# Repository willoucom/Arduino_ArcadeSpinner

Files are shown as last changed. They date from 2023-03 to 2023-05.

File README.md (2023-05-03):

# Arduino_ArcadeSpinner

This project is a modern re-creation of the spinners used in arcades, mainly for brick-breakers like arkanoid for example.

The objective is to offer a feeling close to the original equipment by using components that are easy to obtain.

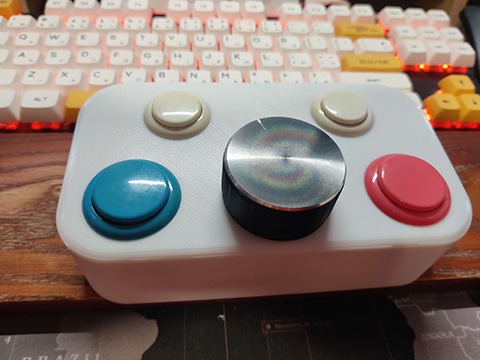
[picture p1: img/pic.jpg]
Img! Arcade Spinner


## In action

### Arkanoid with rotary controller
IMAGE ALT TEXT (http://www.youtube.com/watch?v=QnDsVMLP6zM "Arkanoid with rotary controller on MisterFPGA")

### Puzz'Loop 2 with rotary controller
IMAGE ALT TEXT (http://www.youtube.com/watch?v=TzKd8ytODUM "Puzz'Loop 2 with rotary controller on MisterFPGA")

### Eco Fighter / Ultimate Ecology with rotary controller
IMAGE ALT TEXT (http://www.youtube.com/watch?v=sb1mO-uq1ag "Eco Fighter / Ultimate Ecology with rotary controller on MisterFPGA")

## Usage

By default the device operate as a 4 button controller with Spinner/Paddle attached

You can activate an additional behavior by holding a button when you plug in the device : 

- Press Button0 (Big Left button) to enable MouseX Emulation
- Press Button1 (Big Right button) to enable Paddle Emulation
- Press Button2 (Small Left button) to switch device to mr.Spinner (enabling composite device on mister fpga)
 - In mr.Spinner mode, each button press is redirected to button 1

## MisterFPGA

### Working

| Game | Note|
|--- |--- |
| Arkanoid (World) | |
| Block Gal | |
| Breakout (TTL) | Enable spinner in controls|
| Crater Raider | |
| Dark Planet | |
| Demolition Derby | |
| Discs of Tron | |
| Eco Fighters | Use mr.Spinner mode |
| Forgotten Worlds | Use mr.Spinner mode |
| Kick | |
| Kozmik Krooz'r | |
| Midnight Resistance | Use mr.Spinner mode |
| Moonwar | |
| Pong | Use Paddle emulation and set your player to Paddle |
| Pop'n Bounce (NeoGeo) | Enable Paddle in Dip settings (Soft dip->Pop'n bounce->Controller = paddle) |
| Puzz Loop 2 | Enable Paddle in Service mode (System -> Operation) |
| Tron | |
| Two Tigers (tron conversion)  | |

### Working with workaround
| Game | Note|
|--- |---|
| Block block (world) | Use alternatives/block block (world 910910), must use Mouse Emulation |
| Super Breakout | Enable paddle in controls, must use paddle emulation |

## Mame

You can use the controller with mame and derivative by using the controller in Mouse Emulation mode.

> Note: You can define the default behavior of the controller by modifying the source code, to do this modify the default value of the variable `bool mouse_emu = 0;` to 1t which will have the effect of operating the controller in mouse mode

You need to change the `dial device assignment` option in the mame settings either in mame.ini or using the GUI.

### Edit mame.ini 
```
dial_device               mouse
```
### Using MAME GUI

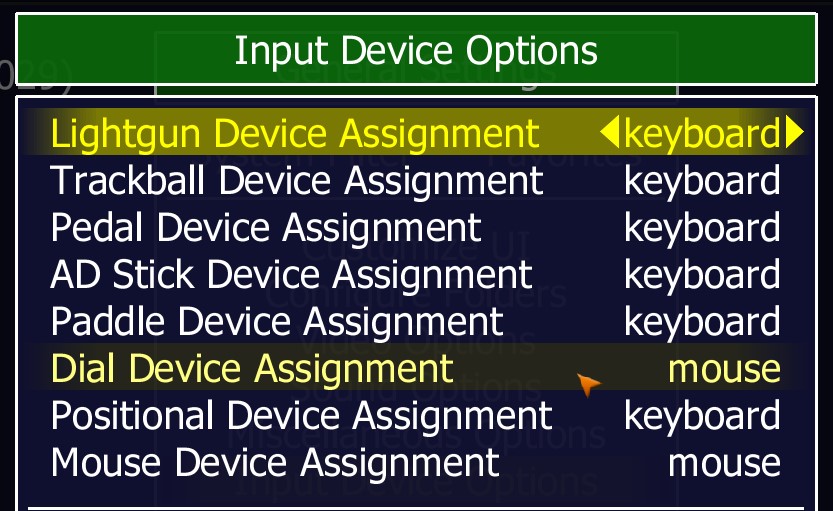
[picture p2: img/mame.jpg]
Img! MAME


## Build yourself

### Parts 

- Rotary encoder (Model: C38S6G5-600B-G24N)
- 40mm Knob with internal diameter of 6mm 
- Arduino Pro Micro
- 2 24mm button
- 2 30mm button
- Enclosure 3D printed or any box

#### Prepare the rotary encoder

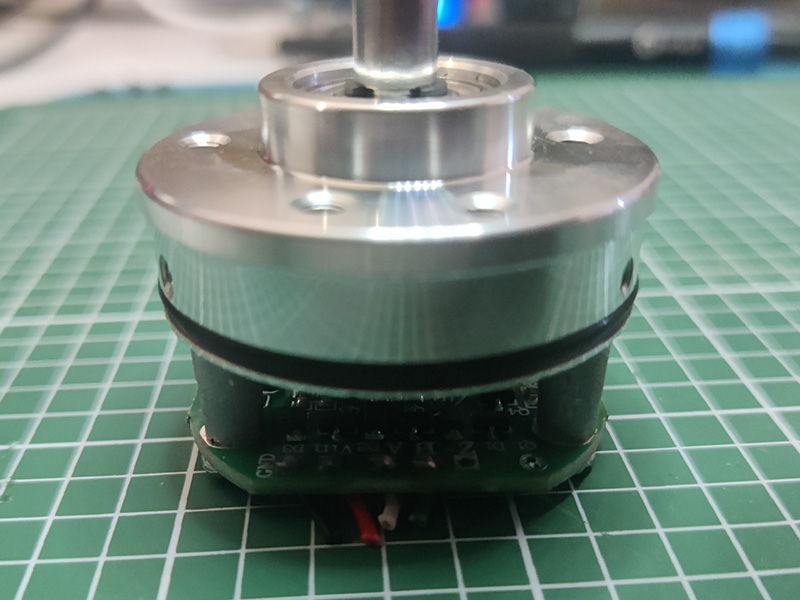
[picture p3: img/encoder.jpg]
Img! rotary encoder


1. Remove the metal enclosure and extract the mechanism.
2. Unsolder all wires.
3. Solder fresh wires on GND, VCC, A and B pads.
4. Recycle the original metal case and wire for another project.

### Arduino Pinout

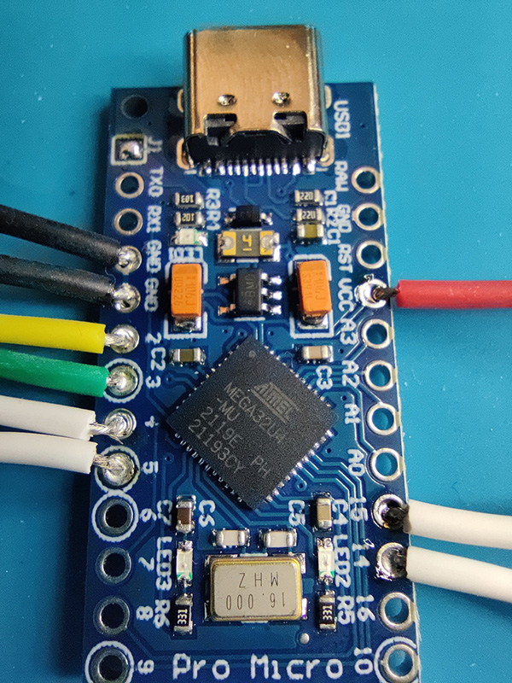
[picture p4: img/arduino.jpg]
Img! Arduino


The buttons must be grounded, you can create a daisy chain to use a common GND for your 4 buttons, you can solder the buttons or use wire connectors.

Bridge pad J1 to send +5v to encoder instead of 3.3v

```
Encoder
GND     GND
VCC     VCC
GP_3    A
GP_2    B

Buttons
GP_5    Button0
GP_4    Button1
GP_15   Button2
GP_14   Button3
```

### Flash your Arduino

1. Install Aduino IDE 2.x
2. Open Arduino_ArcadeSpinner.ino
    1. (Optionnal) Change options in the configuration section.
3. Connect your Arduino pro micro to your computer
4. Select Arduino Leonardo with the correct com port
5. Flash the controller

## Technical informations
In the mister source code there is two special cases

If the device name start by MiSTer-S1 the device is considered as a mr.Spinner

```
// mr.Spinner
// 0x120  - Button
// Axis 7 - EV_REL is spinner
// Axis 8 - EV_ABS is Paddle
// Overlays on other existing gamepads
if (strstr(uniq, "MiSTer-S1")) input[n].quirk = QUIRK_PDSP;
if (strstr(input[n].name, "MiSTer-S1")) input[n].quirk = QUIRK_PDSP;
```

If the device name start by MiSTer-A1 the device is considered as an arcade stick with a spinner and/or paddle
```
// Arcade with spinner and/or paddle:
// Axis 7 - EV_REL is spinner
// Axis 8 - EV_ABS is Paddle
// Includes other buttons and axes, works as a full featured gamepad.
if (strstr(uniq, "MiSTer-A1")) input[n].quirk = QUIRK_PDSP_ARCADE;
if (strstr(input[n].name, "MiSTer-A1")) input[n].quirk = QUIRK_PDSP_ARCADE;
```

## Rotary encoder

The rotary encoder uses a magnet to detect rotation, it translates the orientation into pulses which are then interpreted by the arduino controller.

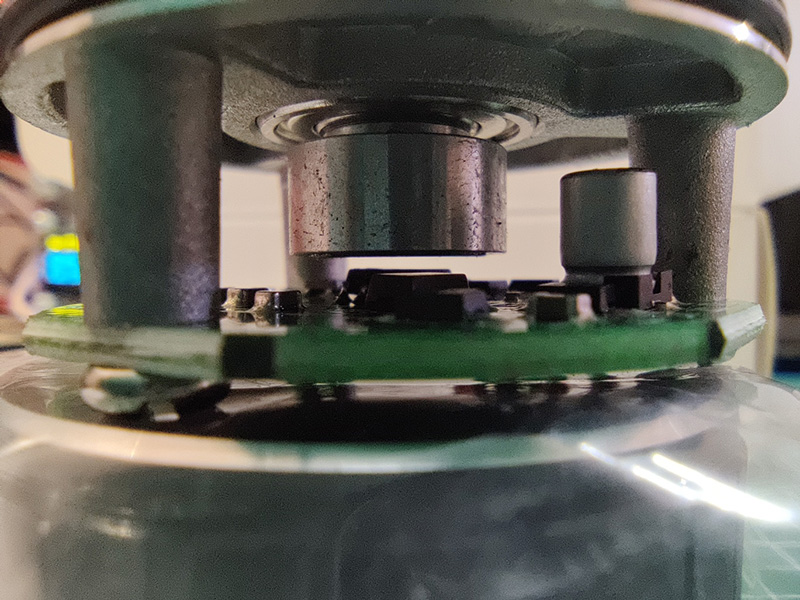
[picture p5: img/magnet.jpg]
Img! Magnet view

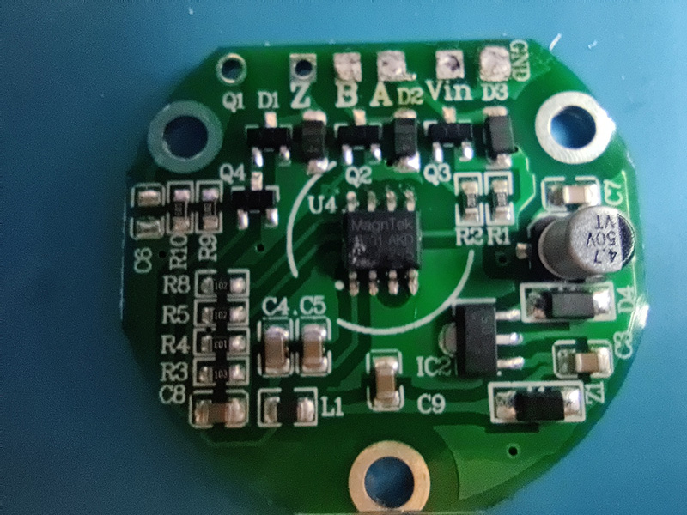
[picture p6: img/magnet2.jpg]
Img! Magnet controller


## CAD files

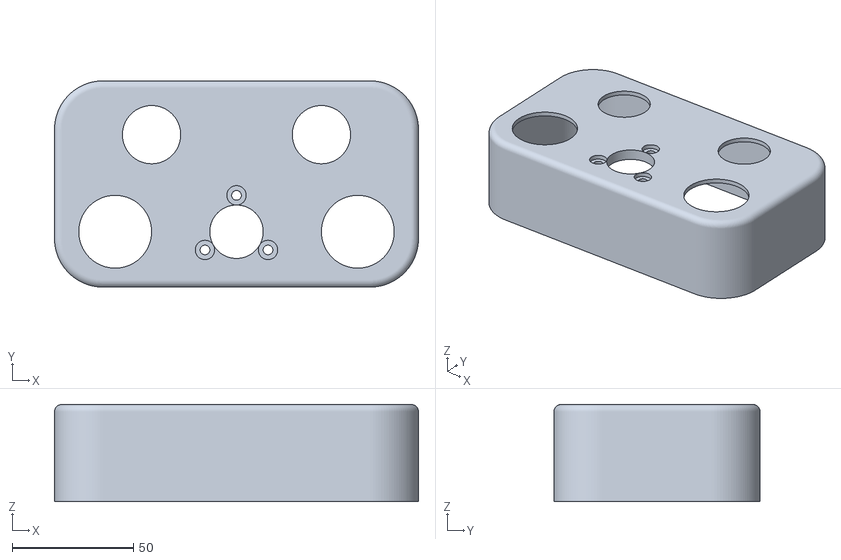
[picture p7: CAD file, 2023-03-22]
3D Files/ArcadeSpinner.stl
150.0 x 85.0 x 40.0

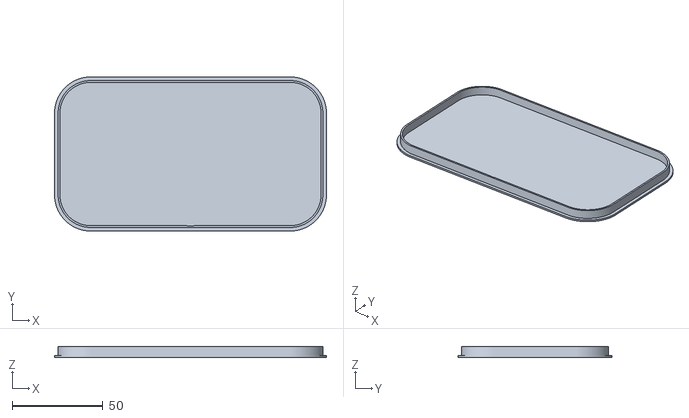
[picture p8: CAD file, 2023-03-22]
3D Files/ArcadeSpinner_bottom.stl
150.0 x 85.0 x 6.00

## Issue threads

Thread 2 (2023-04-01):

LS-30 Titles listed

atrac17, 2023-04-01:
Help me understand why you have LS-30 titles listed? Of course they don't work. They aren't games that use a spinner. Even if we were to support a spinner, how the fuck would you play them?

willoucom, 2023-04-01:
Hello,

For some reason I managed to get Midnight Resistance to work with the spinner (in a weird, almost unplayable way)
I have listed other games using the same control scheme just in case.

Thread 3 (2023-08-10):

Works perfectly in Windows, nothing in MiSTer no spinner nor buttons.

opcow, 2023-08-10:
The buttons and encoder work in Windows. In the game controllers control panel the axis shows as "Dial" and all buttons are functional. In mouse mode  the spinner acts as a mouse X axis, as expected. MiSTer doesn't recognize any input. I made no source code changes.

Some output from `lsusb` and `dmesg` (device ID changed because I had plug cycled a few times).

```/root# lsusb
Bus 003 Device 001: ID 1d6b:0003 Linux Foundation 3.0 root hub
Bus 002 Device 001: ID 1d6b:0002 Linux Foundation 2.0 root hub
Bus 001 Device 011: ID 1b4f:9206 SparkFun SparkFun Pro Micro
Bus 001 Device 005: ID 090c:1000 Silicon Motion, Inc. - Taiwan (formerly Feiya Technology Corp.) Flash Drive
Bus 001 Device 002: ID 1a40:0201 Terminus Technology Inc. FE 2.1 7-port Hub
Bus 001 Device 001: ID 1d6b:0002 Linux Foundation 2.0 root hub

/root# dmesg |tail -16
[ 1387.481765] usb 1-1.5: new full-speed USB device number 11 using dwc2
[ 1387.581905] usb 1-1.5: New USB device found, idVendor=1b4f, idProduct=9206, bcdDevice= 1.00
[ 1387.581929] usb 1-1.5: New USB device strings: Mfr=1, Product=2, SerialNumber=3
[ 1387.581942] usb 1-1.5: Product: SparkFun Pro Micro
[ 1387.581952] usb 1-1.5: Manufacturer: SparkFun
[ 1387.581960] usb 1-1.5: SerialNumber: HIDGDMiSTer-A1 Spinner
[ 1387.584221] cdc_acm 1-1.5:1.0: ttyACM0: USB ACM device
[ 1387.588977] HID usage: 0x00010002, original interval: 1
[ 1387.588998] HID usage: 0x00010002, applied interval: 1
[ 1387.589213] input: SparkFun SparkFun Pro Micro as /devices/platform/soc/ffb40000.usb/usb1/1-1/1-1.5/1-1.5:1.2/0003:1B4F:9206.000E/input/input14
[ 1387.643387] hid-generic 0003:1B4F:9206.000E: input,hidraw0: USB HID v1.01 Mouse [SparkFun SparkFun Pro Micro] on usb-ffb40000.usb-1.5/input2
[ 1387.648015] HID usage: 0x00010004, original interval: 1
[ 1387.648046] JS: endpoint->bInterval=1, interval=1
[ 1387.648054] HID usage: 0x00010004, applied interval: 1
[ 1387.648297] input: SparkFun SparkFun Pro Micro as /devices/platform/soc/ffb40000.usb/usb1/1-1/1-1.5/1-1.5:1.3/0003:1B4F:9206.000F/input/input15
[ 1387.649873] hid-generic 0003:1B4F:9206.000F: input,hidraw1: USB HID v1.01 Joystick [SparkFun SparkFun Pro Micro] on usb-ffb40000.usb-1.5/input3

/root# lsusb -s 1:14 -v

Bus 001 Device 014: ID 1b4f:9206 SparkFun SparkFun Pro Micro
Device Descriptor:
  bLength                18
  bDescriptorType         1
  bcdUSB               2.00
  bDeviceClass          239 Miscellaneous Device
  bDeviceSubClass         2
  bDeviceProtocol         1 Interface Association
  bMaxPacketSize0        64
  idVendor           0x1b4f
  idProduct          0x9206
  bcdDevice            1.00
  iManufacturer           1 SparkFun
  iProduct                2 SparkFun Pro Micro
  iSerial                 3 HIDGDMiSTer-A1 Spinner
```

willoucom, 2023-08-10:
Hi @opcow

I'm guessing you've already added the controller to the Mister's recognized joysticks list, but just in case (and maybe for others), can you check out this guide?
https://boogermann.github.io/Bible_MiSTer/getting-started/inputs/joystick-mapping/

willoucom, 2023-08-10:
I agree with you, the Mister is sometimes difficult to understand.

You can also press the F12 key once the controller is recognized, it resets the assignment and you can reconfigure as you wish, without having a key assigned to the right arrow.

I've been working for a few weeks on an alternative version with a joystick and more buttons, which might be more usable for games like eco fighter and forgotten world. It's still very messy, especially on the layout of the buttons and the spinner, but it's promising.

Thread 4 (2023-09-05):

Spinner does not work on MiSTer in any of the four modes, but works on Windows on all of them.

skooterblog, 2023-09-05:
I bought this spinner from AliExpress: https://s.click.aliexpress.com/e/_DFQ6Pin

It came with firmware where the wheel would work on Windows as a mouse and the buttons as a controller, but on MiSTer only the buttons would work.

I disassembled it to check for the Arduino pins and installed this firmware as it is, except for the Arduino pins which I changed to match my device.

Now the four modes work just fine on Windows, but MiSTer still does nothing when I move the spin, only the four buttons work.

MBL3806-AB-600-5E-2M is the rotary encoder.

Mantics1968, 2025-05-04:
Please help for .HEX ready

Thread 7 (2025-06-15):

VAUS Support for NES (e.g.Arkaniod) / Feature Variable Sensitivity & Mouse Buttons

nad22, 2025-06-15:
First of all thanks for the great project. I just wanted to ask if you have managed to get the spinner working for NES Games like Arkanoid on a Mister FGPA ? I tried all 3 Modes, but the Core does not accept Spinner inputs (Button A works)

Also, I did some minor modifications to get these 3 Features working:

- MouseX Mode: Button 0 and Button 1 act as Mouse Left/Right click,... very useful for Atari Games like Krypton Egg
- MouseX & Mr-Spinner Mode: Button 2 and 3 lower/rise the Mouse/Spinner sensitivity.

Here's the code.

/*
 *  Arduino USB Arcade Spinner
 *  (C) Wilfried JEANNIARD [https://github.com/willoucom]
 *
 *  Based on project by Alexey Melnikov [https://github.com/MiSTer-devel/Retro-Controllers-USB-MiSTer/blob/master/PaddleTwoControllersUSB/PaddleTwoControllersUSB.ino]
 *  Based on project by Mikael Norrgård <mick@daemonbite.com>
 *
 *  GNU GENERAL PUBLIC LICENSE
 *  Version 3, 29 June 2007
 *
 *  This program is free software: you can redistribute it and/or modify
 *  it under the terms of the GNU General Public License as published by
 *  the Free Software Foundation, either version 3 of the License, or
 *  (at your option) any later version.
 *
 *  This program is distributed in the hope that it will be useful,
 *  but WITHOUT ANY WARRANTY; without even the implied warranty of
 *  MERCHANTABILITY or FITNESS FOR A PARTICULAR PURPOSE.  See the
 *  GNU General Public License for more details.
 *
 *  You should have received a copy of the GNU General Public License
 *  along with this program.  If not, see <https://www.gnu.org/licenses/>.
 *
 */

///////////////// Customizable settings /////////////////////////
// For debug (check serial monitor)
// #define DEBUG

// Spinner pulses per revolution
#define SPINNER_PPR 600

// Spinner/Mouse sensitivity
// 1 is more sensitive
// 999 is less sensitive
int spinner_sensitivity = 15;
int mouse_sensitivity = 5;

/////////////////////////////////////////////////////////////////

// Pins used by encoder
#define pinA 3
#define pinB 2
// Pins used by buttons
#define Button0 5 // Left button
#define Button1 4 // Right button
#define Button2 15 // Small Left: Select/Coin
#define Button3 14 // Small Right: Start

////////////////////////////////////////////////////////

// ID for special support in MiSTer
// ATT: 20 chars max (including NULL at the end) according to Arduino source code.
// Additionally serial number is used to differentiate arduino projects to have different button maps!
const char *gp_serial = "MiSTer-A1 Spinner";

#include <Mouse.h>
#include "Gamepad.h"

// Create Gamepad
Gamepad_ Gamepad;
GamepadReport rep;

// Default virtual spinner position
int16_t drvpos = 0;
// Default real spinner position
int16_t r_drvpos = 0;
// Default virtual mouse position
int16_t m_drvpos = 0;

// Variables for paddle_emu
#define SP_MAX ((SPINNER_PPR*4*270UL)/360)
int32_t sp_clamp = SP_MAX/2;

// For emulation
bool mouse_emu = 0;
bool paddle_emu = 0;
bool mr_spinner_emu = 0;

// Interrupt pins of Rotary Encoder
void drv_proc()
{
  static int8_t prev = drvpos;
  int8_t a = digitalRead(pinA);
  int8_t b = digitalRead(pinB);

  int8_t spval = (b << 1) | (b^a);
  int8_t diff = (prev - spval)&3;

  if(diff == 1)
  {
    r_drvpos += 1;
    if(sp_clamp < SP_MAX) sp_clamp++;
  }
  if(diff == 3)
  {
    r_drvpos -= 1;
    if(sp_clamp > 0) sp_clamp--;
  }

  drvpos = r_drvpos / spinner_sensitivity;
  m_drvpos = r_drvpos / mouse_sensitivity;

  prev = spval;
}

// Run at startup
void setup()
{
  #ifdef DEBUG
    Serial.begin(9600);
  #endif
  Gamepad.reset();

  // Encoder
  pinMode(pinA, INPUT_PULLUP);
  pinMode(pinB, INPUT_PULLUP);
  // Init encoder reading
  drv_proc();
  // Attach interrupt to each pin of the encoder
  attachInterrupt(digitalPinToInterrupt(pinA), drv_proc, CHANGE);
  attachInterrupt(digitalPinToInterrupt(pinB), drv_proc, CHANGE);

  // Initialize Button Pins
  pinMode(Button0, INPUT_PULLUP);
  pinMode(Button1, INPUT_PULLUP);
  pinMode(Button2, INPUT_PULLUP);
  pinMode(Button3, INPUT_PULLUP);

  // Enable mouse emulation
  if (!digitalRead(Button0)) {
    mouse_emu = !mouse_emu;
    Mouse.begin();
  }
  // Enable paddle emulation
  if (!digitalRead(Button1)) {
    paddle_emu = !paddle_emu;
  }
  // Spinner only (AKA mr.Spinner mode)
  if (!digitalRead(Button2)) {
    // Announce the device as mr.Spinner (more explanations in the readme file)
    mr_spinner_emu = !mr_spinner_emu;
    gp_serial = "MiSTer-S1 Spinner";
  }

}

// Main loop
void loop()
{
 // Maus-Sensitivität per Button3 (--) und Button2 (++) anpassen
static uint32_t lastSensChange = 0;
uint32_t now = millis();
if (mouse_emu && now - lastSensChange > 200) {
  if (!digitalRead(Button3)) { // Jetzt Button3 = empfindlicher
    if (mouse_sensitivity > 1) {
      mouse_sensitivity--;
      lastSensChange = now;
    }
  }
  if (!digitalRead(Button2)) { // Jetzt Button2 = weniger empfindlich
    if (mouse_sensitivity < 100) {
      mouse_sensitivity++;
      lastSensChange = now;
    }
  }
}
// Spinner-Sensitivität per Button3 (--) und Button2 (++) anpassen im mr-spinner Modus
static uint32_t lastSpinnerChange = 0;
if (mr_spinner_emu && millis() - lastSpinnerChange > 200) {
  if (!digitalRead(Button3)) { // Button3 = empfindlicher
    if (spinner_sensitivity > 1) {
      spinner_sensitivity--;
      lastSpinnerChange = millis();
    }
  }
  if (!digitalRead(Button2)) { // Button2 = weniger empfindlich
    if (spinner_sensitivity < 100) {
      spinner_sensitivity++;
      lastSpinnerChange = millis();
    }
  }
}

  // Default Spinner/Paddle position;
  rep.paddle = 0;
  rep.spinner = 0;
  // Buttons
  if (mr_spinner_emu) {
    rep.b0 = !digitalRead(Button0) || !digitalRead(Button1);
  } else {
    rep.b0 = !digitalRead(Button0);
    rep.b1 = !digitalRead(Button1);
    rep.b2 = !digitalRead(Button2);
    rep.b3 = !digitalRead(Button3);
    }

  // spinner rotation
  static uint16_t prev = 0;
  int16_t val = ((int16_t)(drvpos - prev));
  if(val>127) val = 127; else if(val<-127) val = -127;
  rep.spinner = val;
  prev += val;

  // Paddle Emulation
  if(paddle_emu) {
    rep.paddle = ((sp_clamp*255)/SP_MAX);
    rep.spinner = 0;
  }

  // Mouse Emulation
   // Mouse Emulation
  if(mouse_emu) {
    static uint16_t m_prev = 0;
    int16_t val = ((int16_t)(m_drvpos - m_prev));
    if(val>127) val = 127; else if(val<-127) val = -127;
    m_prev += val;
    Mouse.move(val, 0);
    rep.spinner = 0;

    // Maus-Buttons
    if (!digitalRead(Button0)) {
      Mouse.press(MOUSE_LEFT);
    } else {
      Mouse.release(MOUSE_LEFT);
    }

    if (!digitalRead(Button1)) {
      Mouse.press(MOUSE_RIGHT);
    } else {
      Mouse.release(MOUSE_RIGHT);
    }
  }

  // Only report controller state if it has changed
  if (memcmp(&Gamepad._GamepadReport, &rep, sizeof(GamepadReport)))
  {
    #ifdef DEBUG
      // Very verbose debug
      Serial.print(gp_serial); Serial.print(" ");
      Serial.print(drvpos); Serial.print(" ");
      Serial.print(mouse_emu); Serial.print(" ");
      Serial.print(paddle_emu); Serial.print(" ");
      Serial.print(rep.spinner); Serial.print(" ");
      Serial.print(rep.paddle); Serial.print(" ");
      Serial.print(rep.b0); Serial.print(" ");
      Serial.print(rep.b1); Serial.print(" ");
      Serial.print(rep.b2); Serial.print(" ");
      Serial.println(rep.b3);
    #endif
    // Send Gamepad changes
    Gamepad._GamepadReport = rep;
    Gamepad.send();
  }
}

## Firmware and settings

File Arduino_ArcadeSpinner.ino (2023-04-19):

/*  
 *  Arduino USB Arcade Spinner
 *  (C) Wilfried JEANNIARD [https://github.com/willoucom]
 *  
 *  Based on project by Alexey Melnikov [https://github.com/MiSTer-devel/Retro-Controllers-USB-MiSTer/blob/master/PaddleTwoControllersUSB/PaddleTwoControllersUSB.ino]
 *  Based on project by Mikael Norrgård <mick@daemonbite.com>
 *  
 *  GNU GENERAL PUBLIC LICENSE
 *  Version 3, 29 June 2007
 *  
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
 */

///////////////// Customizable settings /////////////////////////
// For debug (check serial monitor)
// #define DEBUG

// Spinner pulses per revolution
#define SPINNER_PPR 600

// Spinner/Mouse sensitivity
// 1 is more sensitive 
// 999 is less sensitive
#define SPINNER_SENSITIVITY 15
#define MOUSE_SENSITIVITY 1

/////////////////////////////////////////////////////////////////

// Pins used by encoder
#define pinA 2
#define pinB 3
// Pins used by buttons
#define Button0 5 // Left button
#define Button1 4 // Right button
#define Button2 15 // Small Left: Select/Coin
#define Button3 14 // Small Right: Start

////////////////////////////////////////////////////////

// ID for special support in MiSTer 
// ATT: 20 chars max (including NULL at the end) according to Arduino source code.
// Additionally serial number is used to differentiate arduino projects to have different button maps!
const char *gp_serial = "MiSTer-A1 Spinner";

#include <Mouse.h>
#include "Gamepad.h"

// Create Gamepad
Gamepad_ Gamepad;
GamepadReport rep;

// Default virtual spinner position
int16_t drvpos = 0;
// Default real spinner position
int16_t r_drvpos = 0;
// Default virtual mouse position
int16_t m_drvpos = 0;

// Variables for paddle_emu
#define SP_MAX ((SPINNER_PPR*4*270UL)/360)
int32_t sp_clamp = SP_MAX/2;

// For emulation
bool mouse_emu = 0;
bool paddle_emu = 0;
bool mr_spinner_emu = 0;

// Interrupt pins of Rotary Encoder
void drv_proc()
{
  static int8_t prev = drvpos;
  int8_t a = digitalRead(pinA);
  int8_t b = digitalRead(pinB);

  int8_t spval = (b << 1) | (b^a);
  int8_t diff = (prev - spval)&3;

  if(diff == 1) 
  {
    r_drvpos += 1;
    if(sp_clamp < SP_MAX) sp_clamp++;
  }
  if(diff == 3) 
  {
    r_drvpos -= 1;
    if(sp_clamp > 0) sp_clamp--;
  }

  drvpos = r_drvpos / SPINNER_SENSITIVITY;
  m_drvpos = r_drvpos / MOUSE_SENSITIVITY;
  prev = spval;
}

// Run at startup
void setup()
{
  #ifdef DEBUG
    Serial.begin(9600);
  #endif
  Gamepad.reset();

  // Encoder
  pinMode(pinA, INPUT_PULLUP);
  pinMode(pinB, INPUT_PULLUP);
  // Init encoder reading
  drv_proc();
  // Attach interrupt to each pin of the encoder
  attachInterrupt(digitalPinToInterrupt(pinA), drv_proc, CHANGE);
  attachInterrupt(digitalPinToInterrupt(pinB), drv_proc, CHANGE);

  // Initialize Button Pins
  pinMode(Button0, INPUT_PULLUP);
  pinMode(Button1, INPUT_PULLUP);
  pinMode(Button2, INPUT_PULLUP);
  pinMode(Button3, INPUT_PULLUP);

  // Enable mouse emulation
  if (!digitalRead(Button0)) {
    mouse_emu = !mouse_emu;
    Mouse.begin();
  } 
  // Enable paddle emulation
  if (!digitalRead(Button1)) {
    paddle_emu = !paddle_emu;
  }
  // Spinner only (AKA mr.Spinner mode)
  if (!digitalRead(Button2)) {
    // Announce the device as mr.Spinner (more explanations in the readme file)
    mr_spinner_emu = !mr_spinner_emu;
    gp_serial = "MiSTer-S1 Spinner";
  }
  
}

// Main loop
void loop()
{
  // Default Spinner/Paddle position;
  rep.paddle = 0;
  rep.spinner = 0;
  // Buttons
  if (mr_spinner_emu) {
    rep.b0 = !digitalRead(Button0) || !digitalRead(Button1) || !digitalRead(Button2) || !digitalRead(Button3);
  } else {
    rep.b0 = !digitalRead(Button0);
    rep.b1 = !digitalRead(Button1);
    rep.b2 = !digitalRead(Button2);
    rep.b3 = !digitalRead(Button3);
    }

  // spinner rotation
  static uint16_t prev = 0;
  int16_t val = ((int16_t)(drvpos - prev));
  if(val>127) val = 127; else if(val<-127) val = -127;
  rep.spinner = val;
  prev += val;

  // Paddle Emulation
  if(paddle_emu) {
    rep.paddle = ((sp_clamp*255)/SP_MAX);
    rep.spinner = 0;
  }

  // Mouse Emulation
  if(mouse_emu) {
    static uint16_t m_prev = 0;
    int16_t val = ((int16_t)(m_drvpos - m_prev));
    if(val>127) val = 127; else if(val<-127) val = -127;
    m_prev += val;
    Mouse.move(val, 0);
    rep.spinner = 0;
  }

  // Only report controller state if it has changed
  if (memcmp(&Gamepad._GamepadReport, &rep, sizeof(GamepadReport)))
  {
    #ifdef DEBUG
      // Very verbose debug
      Serial.print(gp_serial); Serial.print(" ");
      Serial.print(drvpos); Serial.print(" ");
      Serial.print(mouse_emu); Serial.print(" ");
      Serial.print(paddle_emu); Serial.print(" ");
      Serial.print(rep.spinner); Serial.print(" ");
      Serial.print(rep.paddle); Serial.print(" ");
      Serial.print(rep.b0); Serial.print(" ");
      Serial.print(rep.b1); Serial.print(" ");
      Serial.print(rep.b2); Serial.print(" ");
      Serial.println(rep.b3);
    #endif
    // Send Gamepad changes
    Gamepad._GamepadReport = rep;
    Gamepad.send();
  }
}
